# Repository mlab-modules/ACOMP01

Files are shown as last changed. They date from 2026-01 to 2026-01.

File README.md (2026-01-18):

# ACOMP01 - Fast Analog Comparator Module

The ACOMP01 module is a high-speed dual comparator board with differential LVDS outputs. It is designed for fast signal discrimination in nanosecond-scale timing systems. Each comparator features coaxial MCX input connectors and differential output for integration into high-speed digital acquisition or timing logic circuits.

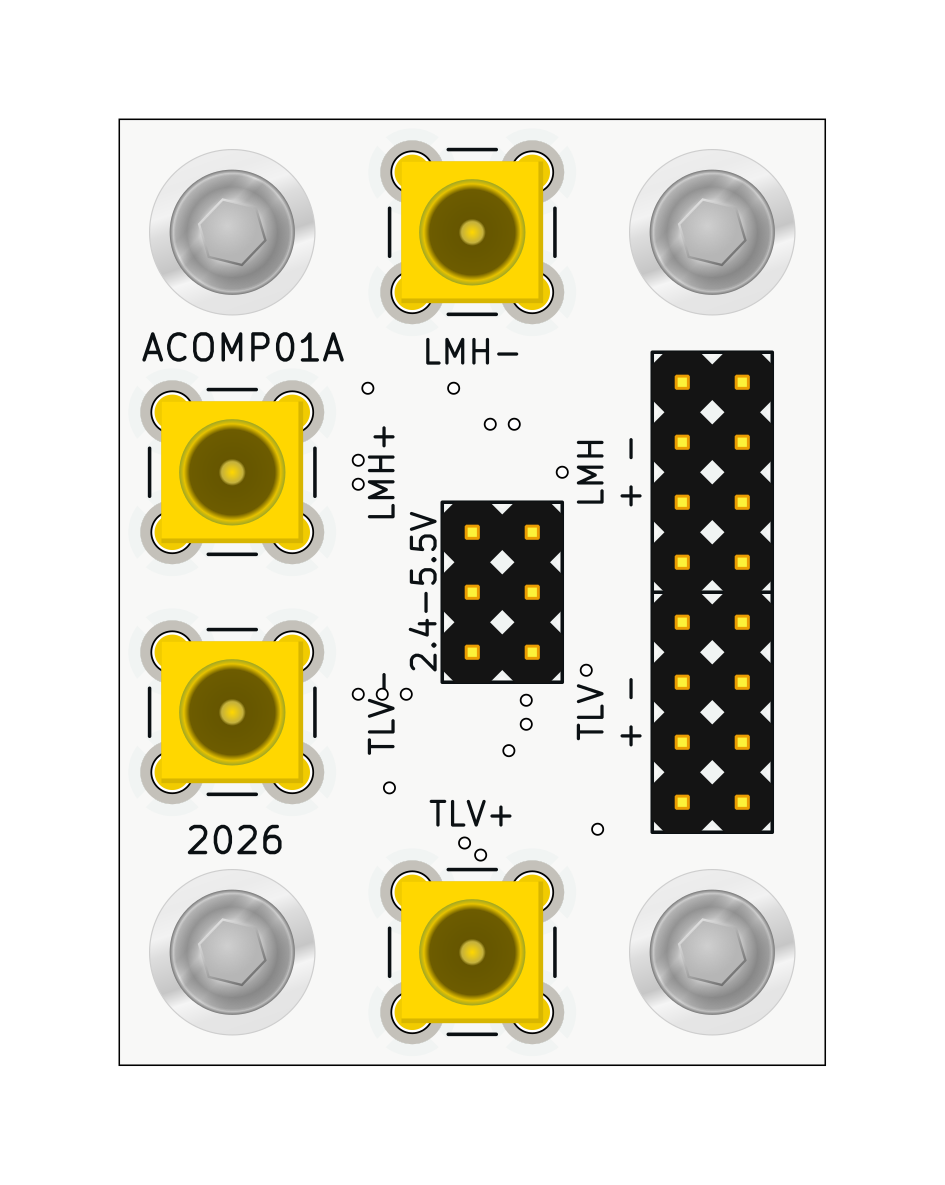
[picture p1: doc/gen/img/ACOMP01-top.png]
ACOMP01 top view
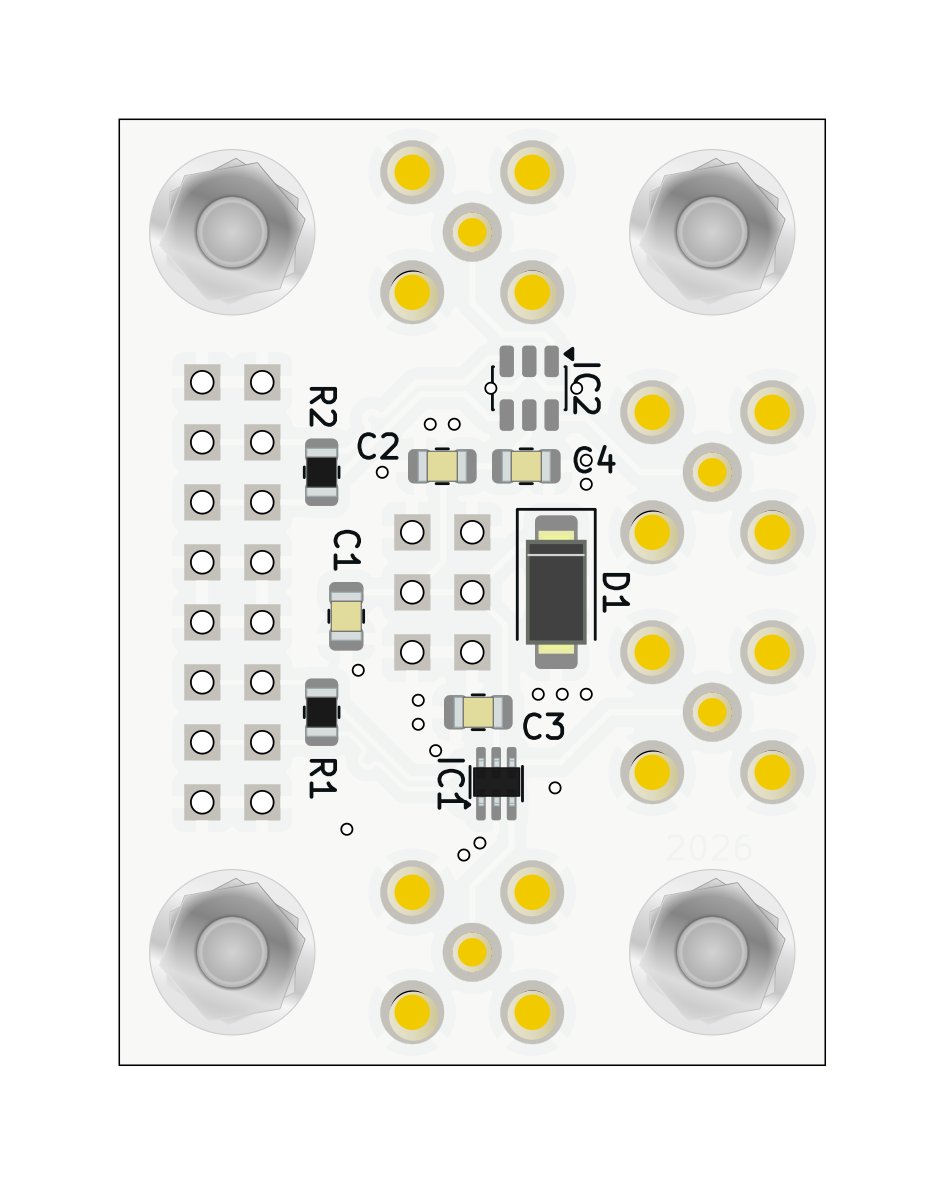
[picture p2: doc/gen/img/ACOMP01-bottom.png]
ACOMP01 bottom view
 

## Typical Applications

- High-speed pulse discrimination
- Oscilloscope triggering
- LIDAR and ToF sensing
- Nuclear and particle physics detectors
- Time interval measurement systems

## Features

- Two independent comparator channels
- High-speed response with sub-nanosecond propagation delay
- Differential LVDS outputs
- MCX connectors for analog input signals
- Designed for precise pulse timing and triggering

## Comparators Used

### TLV3604
- Propagation delay: 800 ps
- Toggle rate: up to 3 Gbps
- Input common-mode range: extends 200 mV beyond rails
- LVDS output with 350 mV typical differential swing
- Supply voltage: 2.4 V to 5.5 V
- Mounted as IC1【9†tlv3604.pdf】

### LMH7220
- Propagation delay: 2.9 ns
- Input voltage range extends 200 mV below ground
- LVDS output designed for 100 Ω differential load
- Supply voltage: 2.7 V to 12 V
- Mounted as IC2【8†lmh7220.pdf】

## Connectors

### Power Supply (J1)

- Onboard filtering capacitors: 10 µF, 1 µF, and 100 nF
- 5.6 V Zener diode for optional input voltage clamping and reverse voltage protection

The module uses (2.4 V to 5.5 V) for the two comparators. Ensure proper voltages are applied as per the comparator requirements.

### Inputs

- **J2, J3**: Inputs for TLV3604 (IN+, IN-)
- **J4, J5**: Inputs for LMH7220 (IN+, IN-)

All inputs are via MCX connectors with ground-referenced shielding.

### Outputs

- **J6**: LVDS differential output from TLV3604 (TLV_OUT+, TLV_OUT-)
- **J7**: LVDS differential output from LMH7220 (LMH_OUT+, LMH_OUT-)

> Each output is routed to a standard 3-pin header: OUT+, GND, OUT-

## Notes

DNF (Do Not Fit) resistors R1 and R2 are placeholders for optional output termination.

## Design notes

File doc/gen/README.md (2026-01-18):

# PCB

Board size: 29.97x40.13 mm (1.18x1.58 inches)

- This is the size of the rectangle that contains the board
- Thickness: 1.6 mm (63 mils)
- Material: FR4
- Finish: None
- Layers: 2
- Copper thickness: 35 µm

Solder mask: TOP / BOTTOM

- Color: Green

Silk screen: TOP / BOTTOM

- Color: White

Stackup:

| Name | Type | Color | Thickness [µm]| Material | Er | Loss tan |
|---|---|---|---|---|---|---|
| F.SilkS | Top Silk Screen | | | | | |
| F.Paste | Top Solder Paste | | | | | |
| F.Mask | Top Solder Mask | | 10 | | | |
| F.Cu | copper | | 35 | | | |
| dielectric 1 | core | | 1510 | FR4 | 4.5 | 0.020 |
| B.Cu | copper | | 35 | | | |
| B.Mask | Bottom Solder Mask | | 10 | | | |
| B.Paste | Bottom Solder Paste  | | | | | |
| B.SilkS | Bottom Silk Screen | | | | | |

# Important sizes

Clearance: 0.2 mm (8 mils)

Track width: 0.2 mm (8 mils)

- By design rules: 0.2 mm (8 mils)

Drill: 0.5 mm (20 mils)

- Vias: 0.5 mm (20 mils) [Design: 0.3 mm (12 mils)]
- Pads: 1.0 mm (39 mils)
- The above values are real drill sizes, they add 0.1 mm (4 mils) to plated holes (PTH)

Via: 0.8/0.4 mm (31/16 mils)

- By design rules: 0.4/0.2 mm (16/8 mils)
- Micro via: yes [0.2/0.1 mm (8/4 mils)]
- Buried/blind via: yes
- Total: 18 (thru: 18 buried/blind: 0 micro: 0)

Outer Annular Ring: 0.15 mm (6 mils)

- By design rules: 0.26 mm (10 mils)

Eurocircuits class: 4B
- Using min drill 0.5 mm for an OAR of 0.15 mm

# General stats

Components count: (SMD/THT)

- Top: 0/11 (THT)
- Bottom: 9/0 (SMD)

Defined tracks:

- 0.25 mm (10 mils)
- 0.3 mm (12 mils)
- 0.4 mm (16 mils)
- 0.5 mm (20 mils)
- 0.6 mm (24 mils)
- 0.8 mm (31 mils)
- 0.86 mm (34 mils)

Used tracks:

- 0.2 mm (8 mils) (21) defined: no
- 0.25 mm (10 mils) (67) defined: yes
- 0.5 mm (20 mils) (2) defined: yes

Defined vias:

Used vias:

- 0.8/0.4 mm (31/16 mils) (Count: 18, Aspect: 2.0 A) defined: no

Holes (excluding vias):

- 0.89 mm (35 mils) (22)
- 1.5 mm (59 mils) (4)
- 1.7 mm (67 mils) (16)
- 3.0 mm (118 mils) (4)

Oval holes:

Drill tools (including vias and computing adjusts and rounding):

- 0.5 mm (20 mils) (18)
- 1.0 mm (39 mils) (22)
- 1.6 mm (63 mils) (4)
- 1.8 mm (71 mils) (16)
- 3.1 mm (122 mils) (4)

Solder paste stats:

Using a paste with 87.75 % alloy, that has an specific gravity for the alloy of 7.4 g/cm³
and 1.0 g/cm³ for the flux. This paste has an specific gravity of  4.15 g/cm³.

The stencil thickness is  0.12 mm.

| Side | Pads with paste | Area [mm²] | Paste [g] |
|---|---|---|---|
| Total  | 26 | 33.29 | 0.17 |

Note: this is just an approximation to the theoretical value. Margins of the solder mask and waste aren't computed.

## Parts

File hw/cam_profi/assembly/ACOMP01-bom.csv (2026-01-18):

Component | Description | Part | References | Value | Footprint | Quantity Per PCB | Datasheet | ust_id | height | mouser part number | mouser price/stock | manufacturer_name | manufacturer_part_number
1 | Unpolarized capacitor | C | C3C4 | 100nF | C_0805_2012Metric | 2 | ~
2 |  | C_Small-Device-ISM02A-rescue | C2 | 1uF | C_0805_2012Metric | 1 |  | C0805_100n
3 |  | C_Small-Device-ISM02A-rescue | C1 | 10uF | C_0805_2012Metric | 1 |  | 5c70984812875079b91f8bbe
4 |  | D_ZENER-MLAB_D | D1 | BZV55C-5,6V | D_SMA | 1 |  | 5c70984512875079b91f88b2
5 | High Speed Comparator with LVDS Output | LMH7220MK_NOPB | IC2 | LMH7220MK_NOPB | SOT-23-6 | 1 | http://www.ti.com/lit/gpn/lmh7220 |  | 1.1 | 926-LMH7220MK/NOPB | https://www.mouser.co.uk/ProductDetail/Texas-Instruments/LMH7220MK-NOPB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 | Texas Instruments | LMH7220MK/NOPB
6 | 800-ps high-speed rail-rail input comparator with LVDS outputs | TLV3604DCKR | IC1 | TLV3604DCKR | SOT-363_SC-70-6 | 1 | https://www.ti.com/lit/gpn/tlv3604 |  | 1.1 | 595-TLV3604DCKR | https://www.mouser.co.uk/ProductDetail/Texas-Instruments/TLV3604DCKR?qs=eP2BKZSCXI640M7VQt%252Bohw%3D%3D | Texas Instruments | TLV3604DCKR
7 | 2x03 2.54 mm pitch header, 2 pins next to each other are connected | HEADER_2x03_PARALLEL | J1 | 2,4 - 5,5V | Straight_2x03 | 1
8 | coaxial connector (BNC, SMA, SMB, SMC, Cinch/RCA, LEMO, ...) | Conn_Coaxial | J2J3J4J5 | Conn_Coaxial | SMA6251A13G50 | 4 | ~
9 | 2x04 2.54 mm pitch header, 2 pins next to each other are connected | HEADER_2x04_PARALLEL | J6J7 | HEADER_2x04_PARALLEL | Straight_2x04 | 2

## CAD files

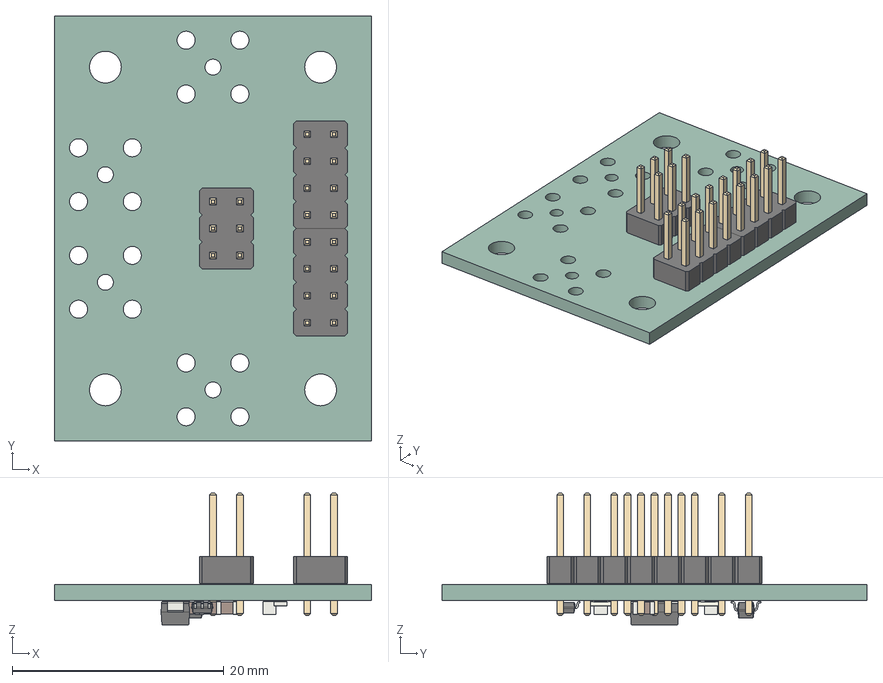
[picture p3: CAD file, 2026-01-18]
doc/gen/ACOMP01.step
30.0 x 40.1 x 12.4 mm
PinHeader_2x04_P2.54mm_Vertical x 2
PinHeader_2x03_P2.54mm_Vertical
C_0805_2012Metric x 4
D_SMA
R_0805_2012Metric x 2
SOT-23-6
SOT-363_SC-70-6
kibot_nozgsteh_PCB

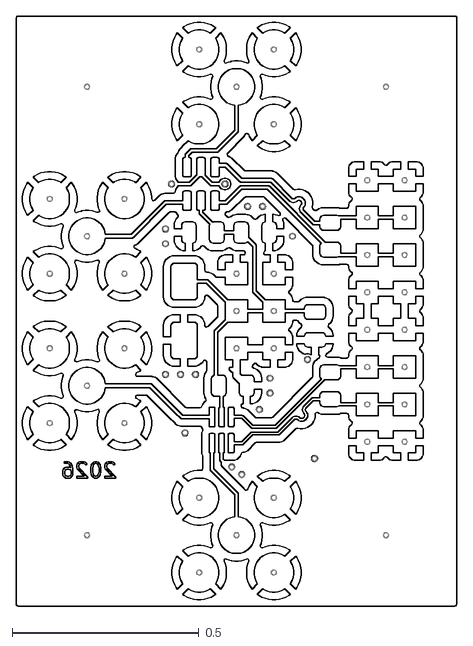
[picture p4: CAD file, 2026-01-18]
doc/gen/dxf/ACOMP01-B_Cu.dxf
1.18 x 1.58

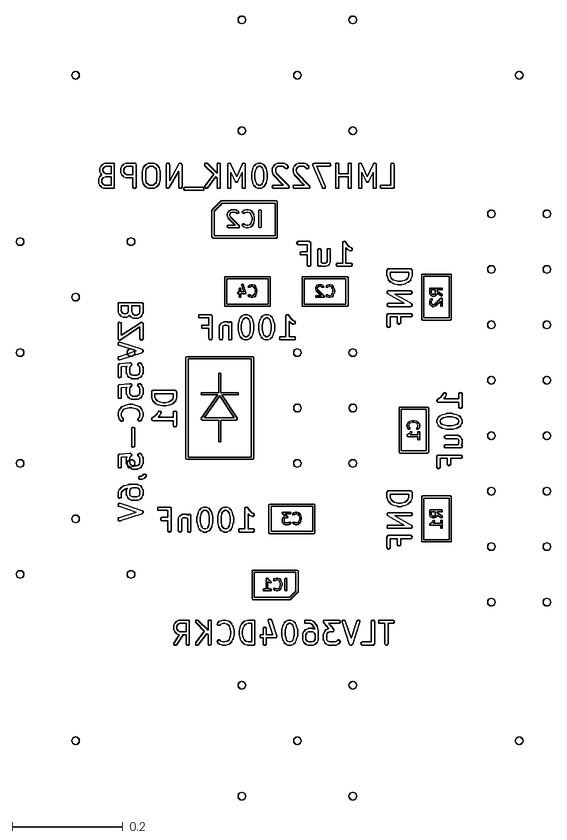
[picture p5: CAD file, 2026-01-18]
doc/gen/dxf/ACOMP01-B_Fab.dxf
0.964 x 1.41

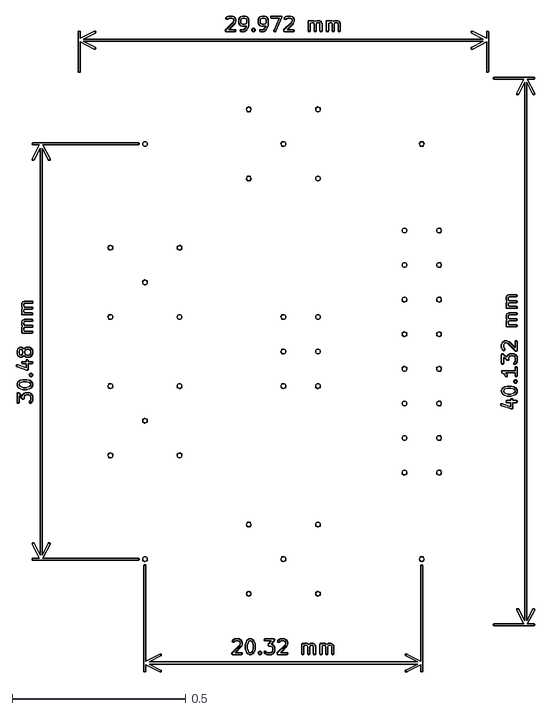
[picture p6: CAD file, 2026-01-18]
doc/gen/dxf/ACOMP01-User_Comments.dxf
1.50 x 1.90

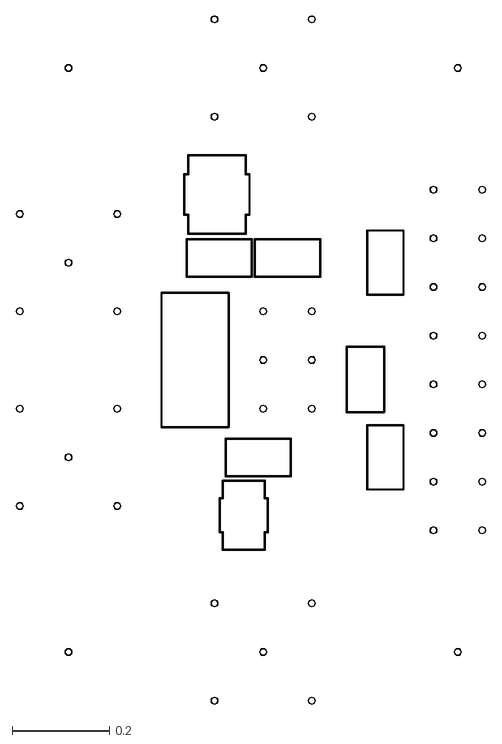
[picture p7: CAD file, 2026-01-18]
doc/gen/dxf/ACOMP01-B_Courtyard.dxf
0.964 x 1.41

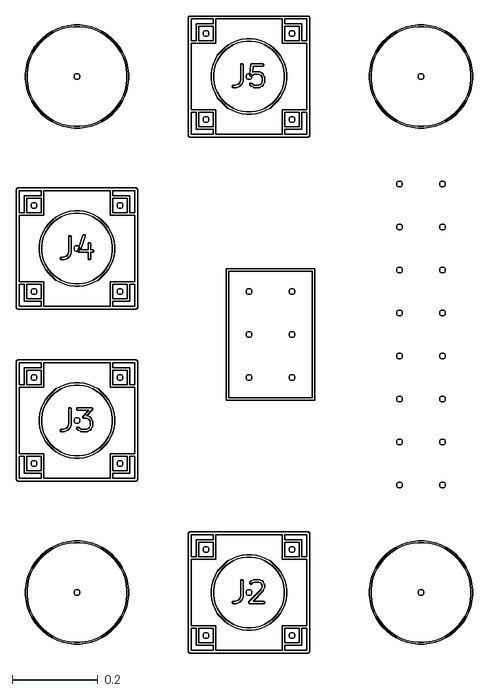
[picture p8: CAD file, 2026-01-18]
doc/gen/dxf/ACOMP01-F_Fab.dxf
1.06 x 1.48

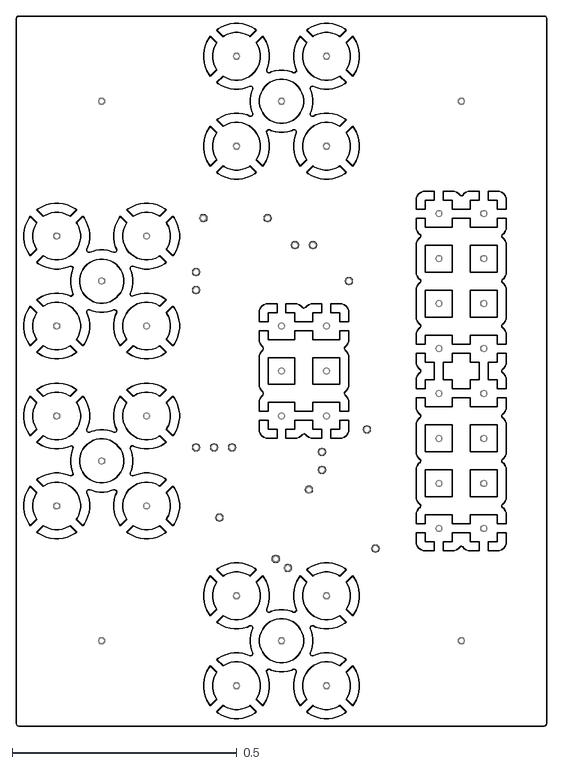
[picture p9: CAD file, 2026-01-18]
doc/gen/dxf/ACOMP01-F_Cu.dxf
1.18 x 1.58

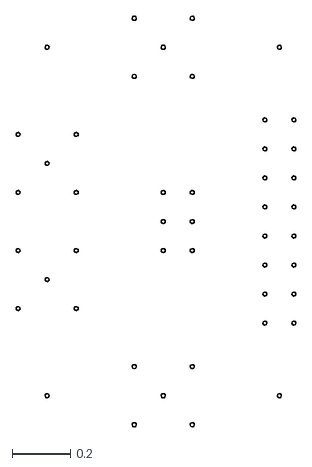
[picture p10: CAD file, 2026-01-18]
doc/gen/dxf/ACOMP01-B_Adhesive.dxf
0.964 x 1.41

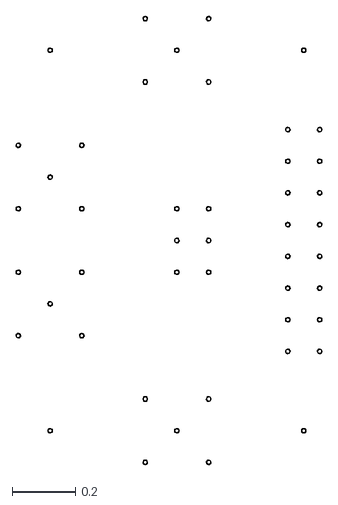
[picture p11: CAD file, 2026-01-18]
doc/gen/dxf/ACOMP01-User_1.dxf
0.964 x 1.41

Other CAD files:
doc/gen/dxf/ACOMP01-B_Mask.dxf
doc/gen/dxf/ACOMP01-B_Paste.dxf
doc/gen/dxf/ACOMP01-B_Silkscreen.dxf
doc/gen/dxf/ACOMP01-Edge_Cuts.dxf
doc/gen/dxf/ACOMP01-F_Mask.dxf
doc/gen/dxf/ACOMP01-F_Silkscreen.dxf

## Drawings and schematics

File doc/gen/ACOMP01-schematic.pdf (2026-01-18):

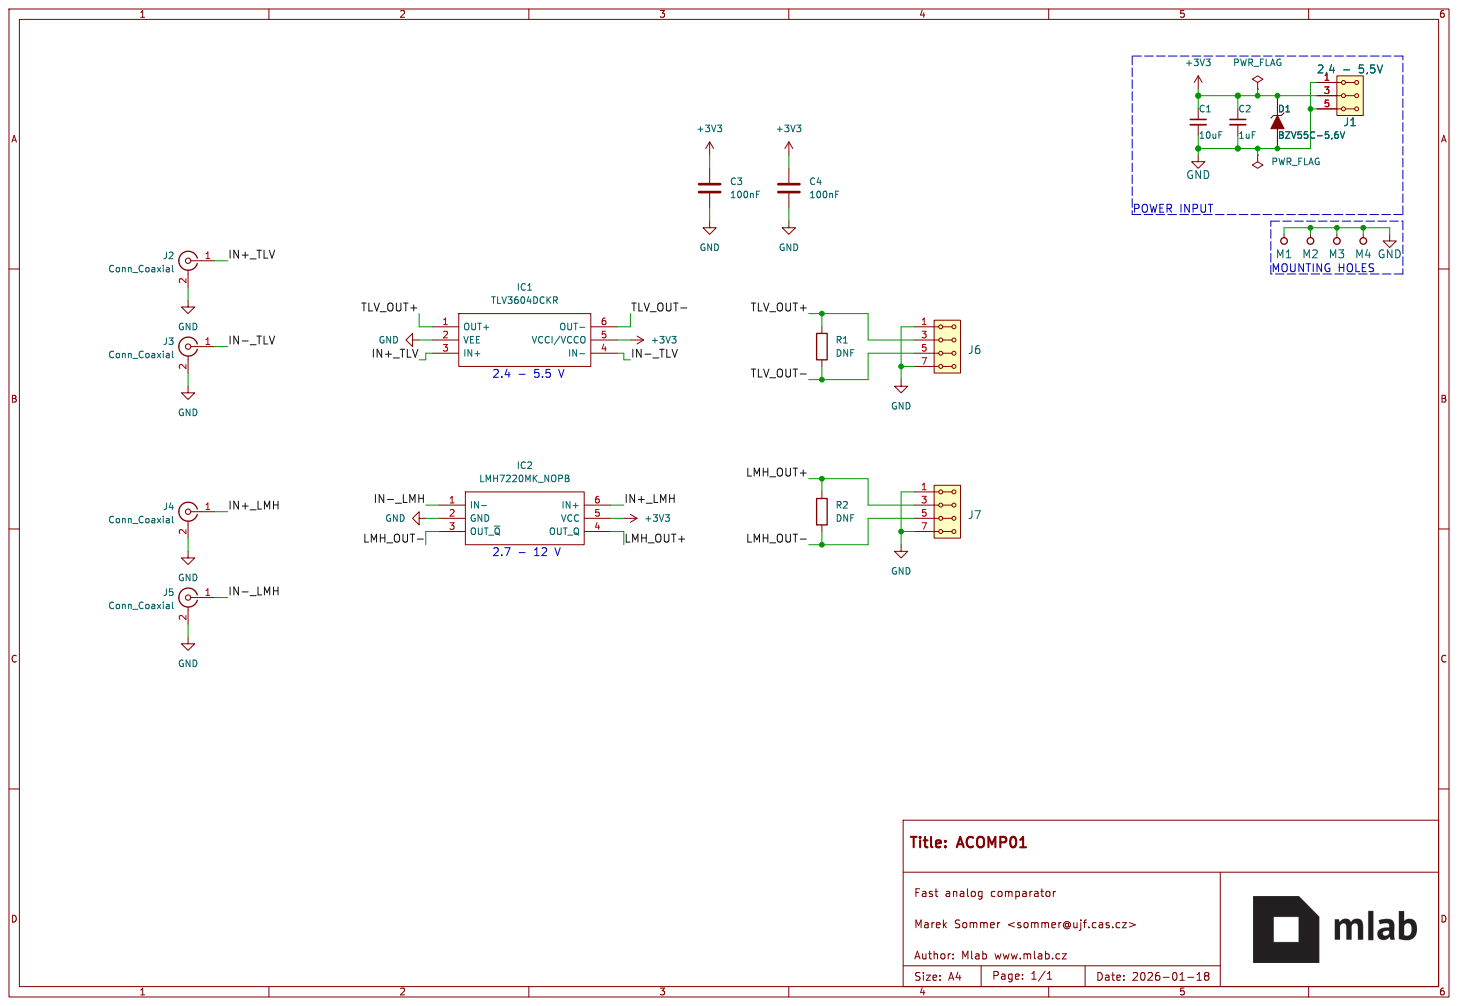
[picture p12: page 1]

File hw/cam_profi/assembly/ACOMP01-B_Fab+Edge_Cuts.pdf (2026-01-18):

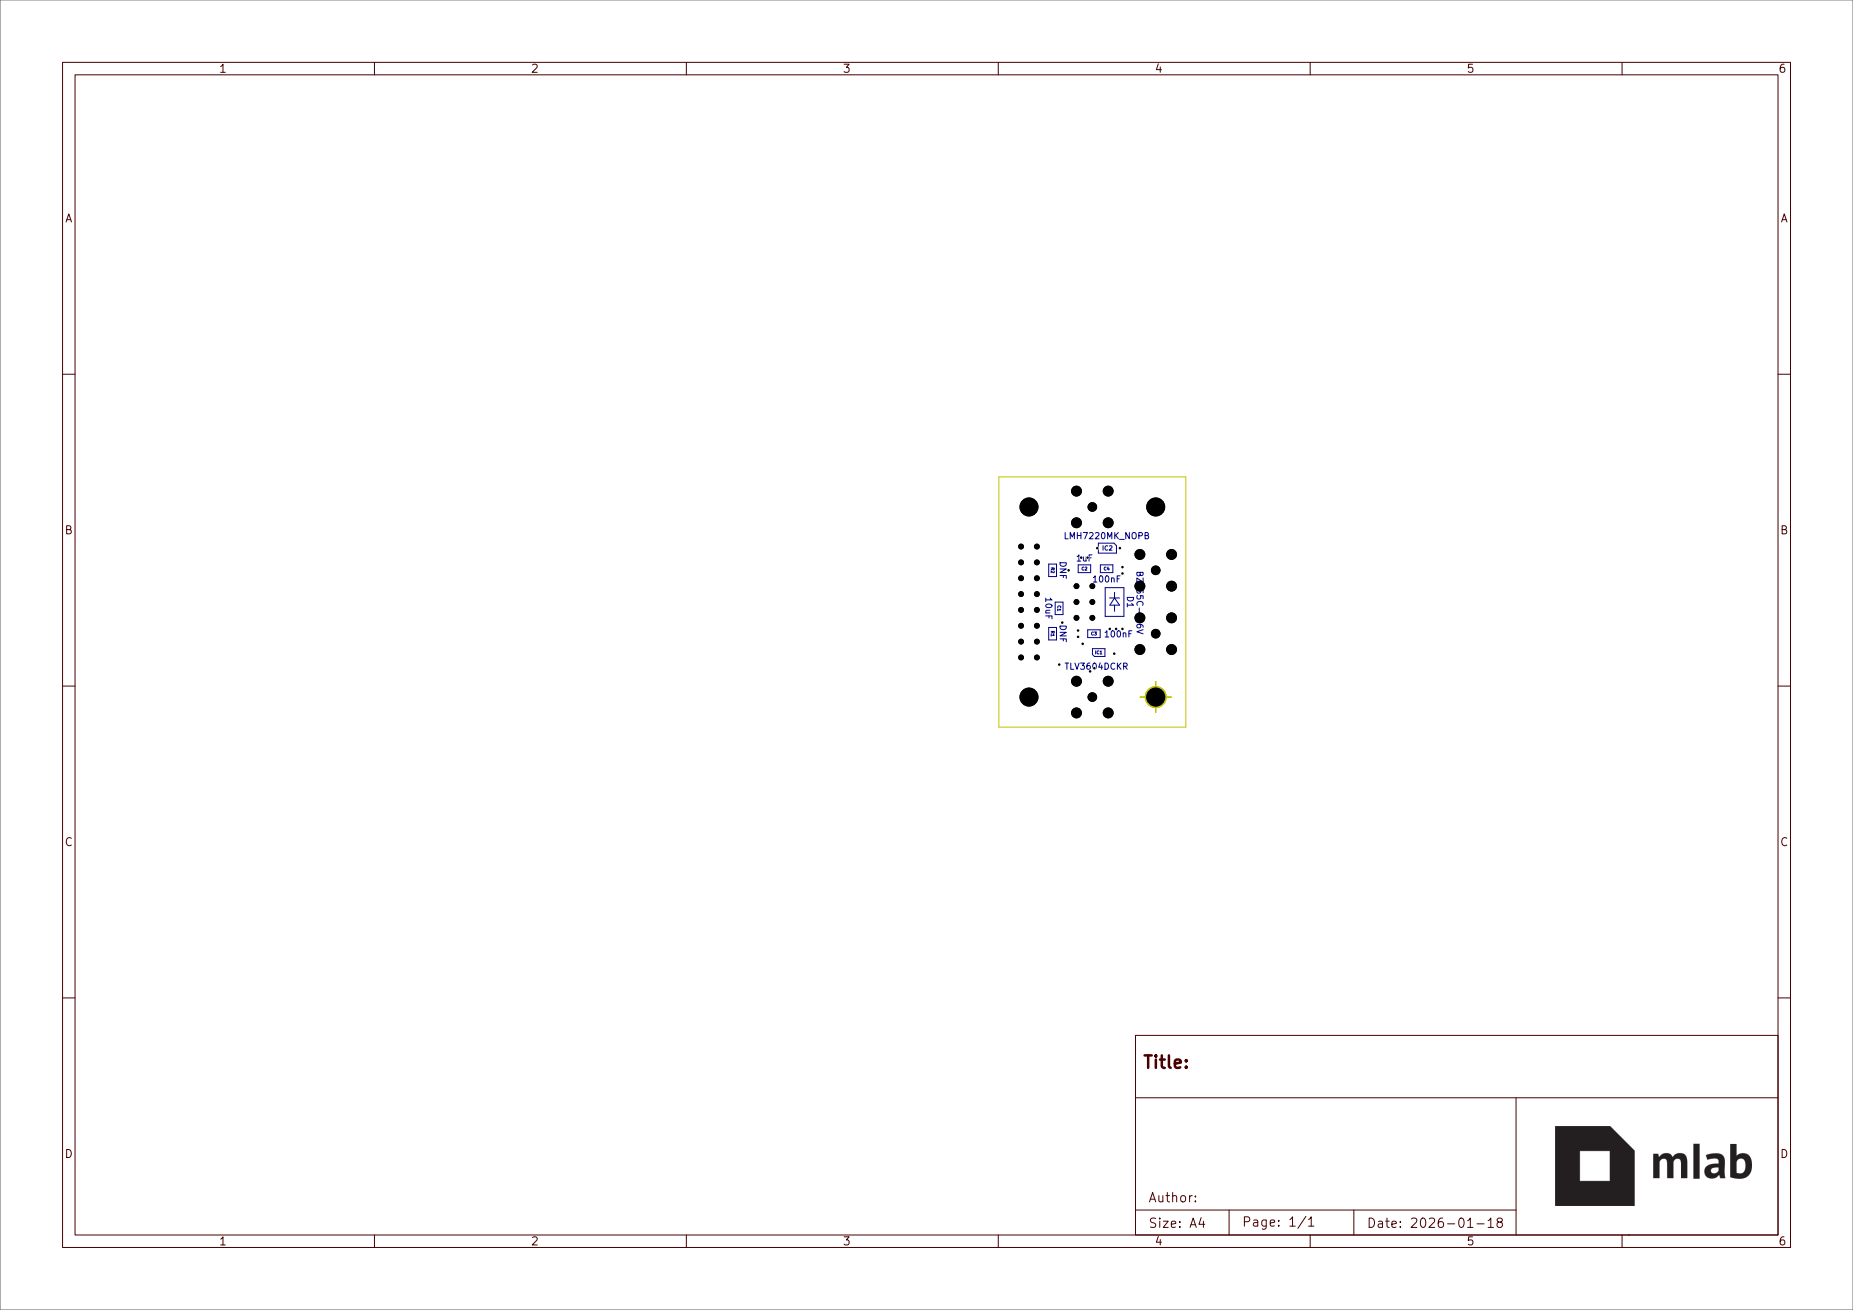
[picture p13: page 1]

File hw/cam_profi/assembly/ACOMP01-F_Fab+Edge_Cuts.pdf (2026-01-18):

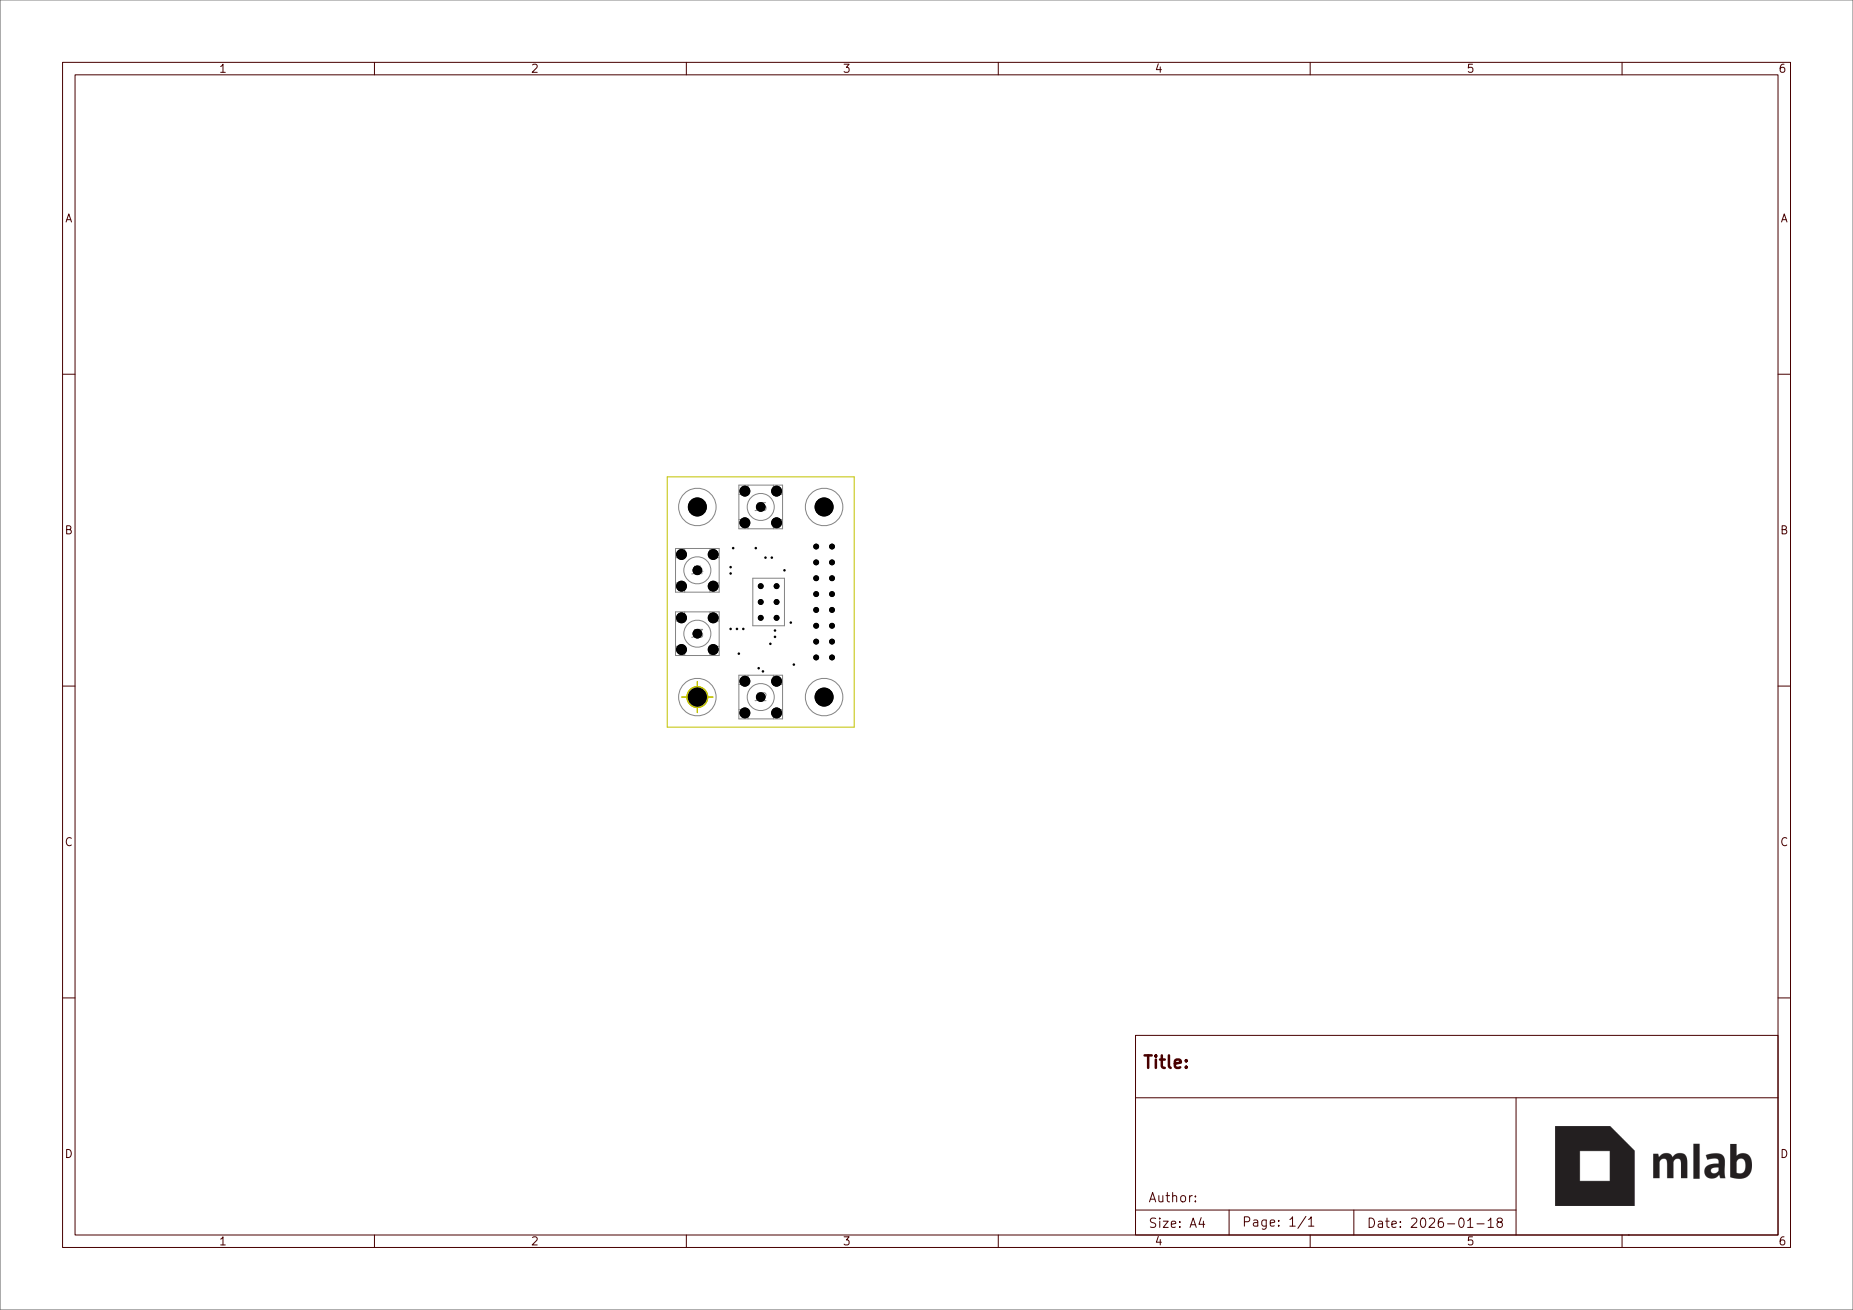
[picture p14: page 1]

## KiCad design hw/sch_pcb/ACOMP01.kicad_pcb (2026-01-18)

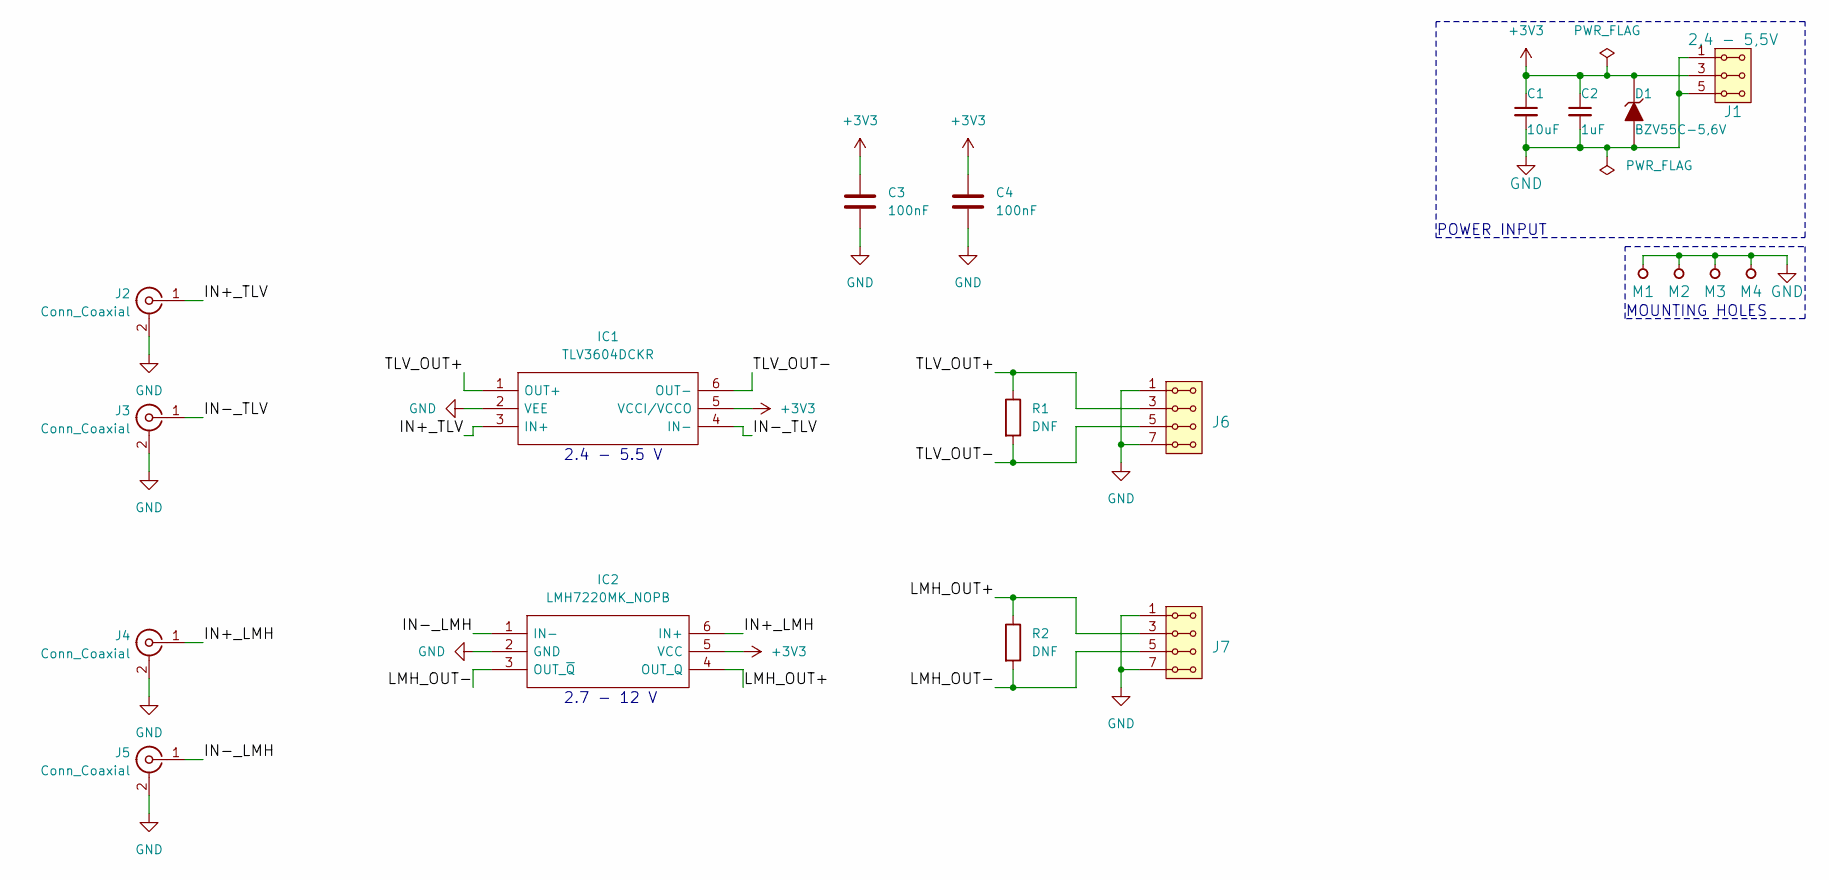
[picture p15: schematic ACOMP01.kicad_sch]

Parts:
C1: 10uF; C_0805_2012Metric
C2: 1uF; C_0805_2012Metric
C3, C4: 100nF; C_0805_2012Metric
D1: BZV55C-5,6V; D_SMA
IC1: TLV3604DCKR; SOT-363_SC-70-6; Mouser Part Number 595-TLV3604DCKR
IC2: LMH7220MK_NOPB; SOT-23-6; Mouser Part Number 926-LMH7220MK/NOPB
J1: 2,4 - 5,5V; Straight_2x03
J2, J3, J4, J5: Conn_Coaxial; SMA6251A13G50
J6, J7: HEADER_2x04_PARALLEL; Straight_2x04
M1, M2: HOLE M3; MountingHole_3mm
M3, M4: HOLE; MountingHole_3mm
R1, R2: DNF; R_0805_2012Metric

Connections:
+3V3: C1.1, C2.1, C3.1, C4.1, D1.1 (K), IC1.5 (VCCI/VCCO), IC2.5 (VCC), J1.3, J1.4
/IN+_LMH: IC2.6 (IN+), J4.1 (In)
/IN+_TLV: IC1.3 (IN+), J2.1 (In)
/IN-_LMH: IC2.1 (IN-), J5.1 (In)
/IN-_TLV: IC1.4 (IN-), J3.1 (In)
/LMH_OUT+: IC2.4 (OUT_Q), J7.3, J7.4, R2.1
/LMH_OUT-: IC2.3 (OUT_~Q), J7.5, J7.6, R2.2
/TLV_OUT+: IC1.1 (OUT+), J6.3, J6.4, R1.1
/TLV_OUT-: IC1.6 (OUT-), J6.5, J6.6, R1.2
GND: C1.2, C2.2, C3.2, C4.2, D1.2 (A), IC1.2 (VEE), IC2.2 (GND), J1.1, J1.2, J1.5, J1.6, J2.2 (Ext), J3.2 (Ext), J4.2 (Ext), J5.2 (Ext), J6.1, J6.2, J6.7, J6.8, J7.1, J7.2, J7.7, J7.8, M1.1, M2.1, M3.1, M4.1

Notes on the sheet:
POWER INPUT
2.4 - 5.5 V
MOUNTING HOLES
2.7 - 12 V

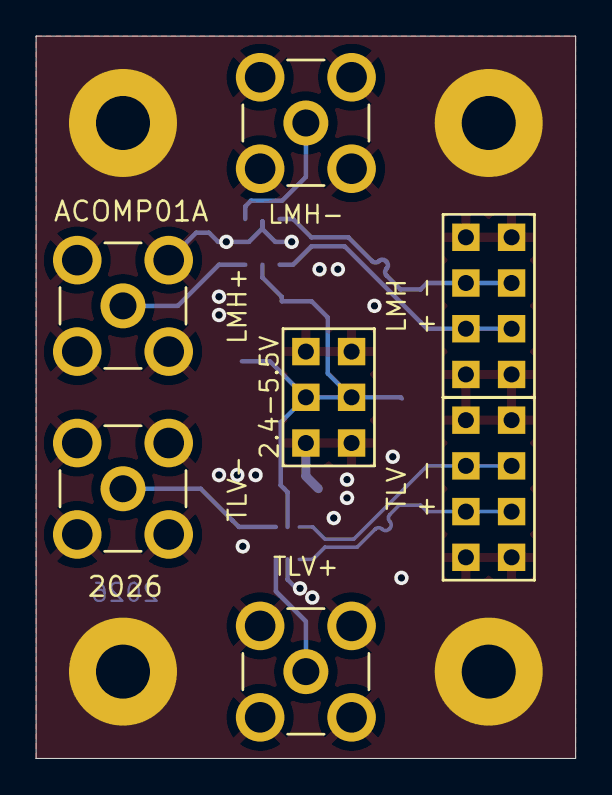
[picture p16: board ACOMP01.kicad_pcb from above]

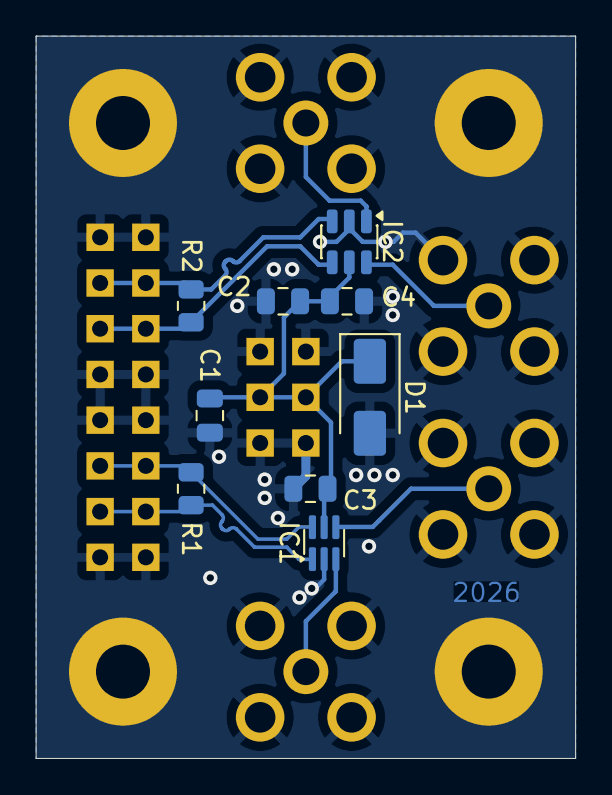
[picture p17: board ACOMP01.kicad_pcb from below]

Board: 2 copper layers, 30.0 x 40.1 mm, 20 parts (9 on the bottom side), 10 nets.

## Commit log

2023-02-09 schematics added
    [ACOMP01.kicad_pcb, ACOMP01.kicad_sch]
2023-02-09 Update actions products
    [ACOMP01-B_Adhesive.dxf, ACOMP01-B_Courtyard.dxf, ACOMP01-B_Cu.dxf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]
2023-02-11 Cleanup and remove unused kicad worksheet template.
    [ACOMP01.kicad_sch]
2023-04-12 pcb layout
    [ACOMP01.kicad_pcb, ACOMP01.kicad_sch]
2023-04-13 pcb layout finished, ready for check
    [ACOMP01-B_Courtyard.dxf, ACOMP01-B_Cu.dxf, ACOMP01-B_Fab.dxf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]
2023-06-09 Cleanup of some DRC errors.
    [ACOMP01.kicad_pcb, ACOMP01.kicad_sch]
2026-01-18 Update project to KiCADv9. Resolved #1
    [ACOMP01.kicad_pcb, ACOMP01.kicad_sch]
2026-01-18 Improve documentation.
    [ACOMP01.kicad_pcb]
